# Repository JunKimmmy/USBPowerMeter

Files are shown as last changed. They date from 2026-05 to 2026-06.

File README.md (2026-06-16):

# USB-C Power Meter

<p align="center">
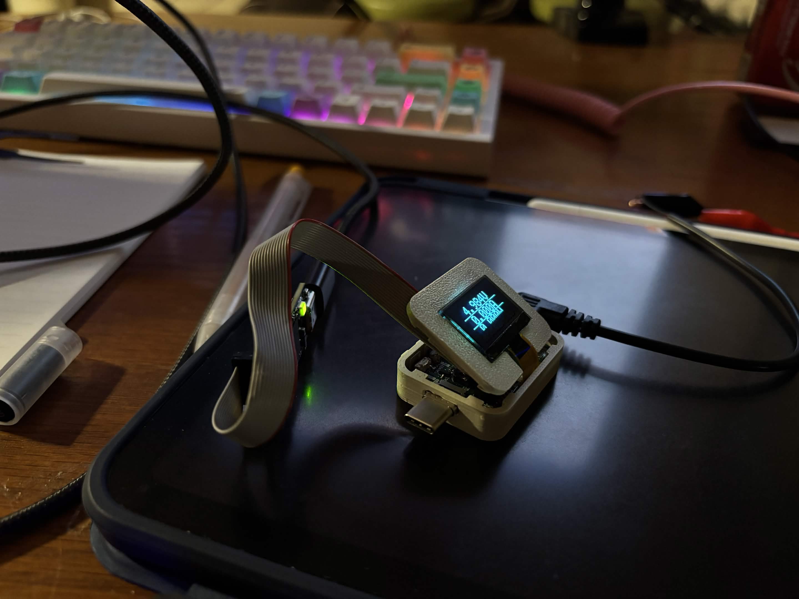
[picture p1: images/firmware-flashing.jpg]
Device running in enclosure
  
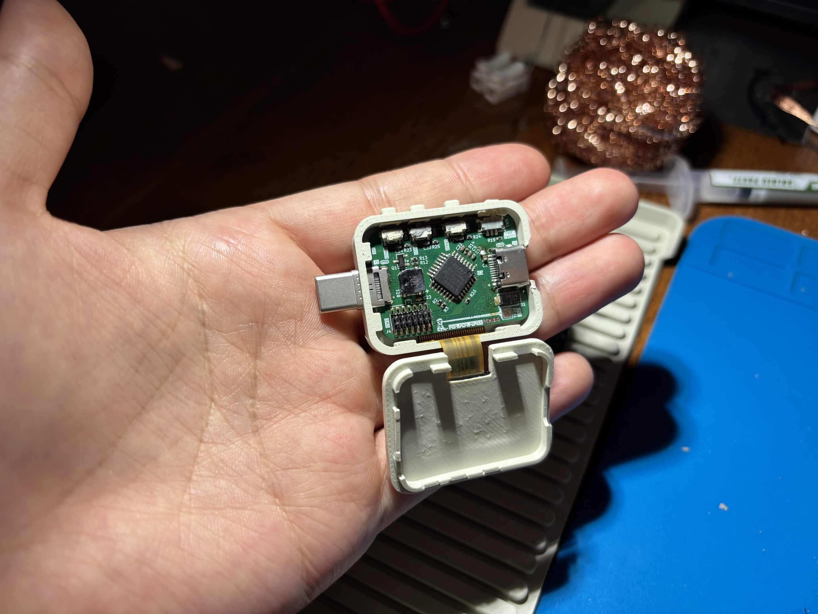
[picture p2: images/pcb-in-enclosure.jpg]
PCB inside open enclosure
  
</p>
<p align="center">
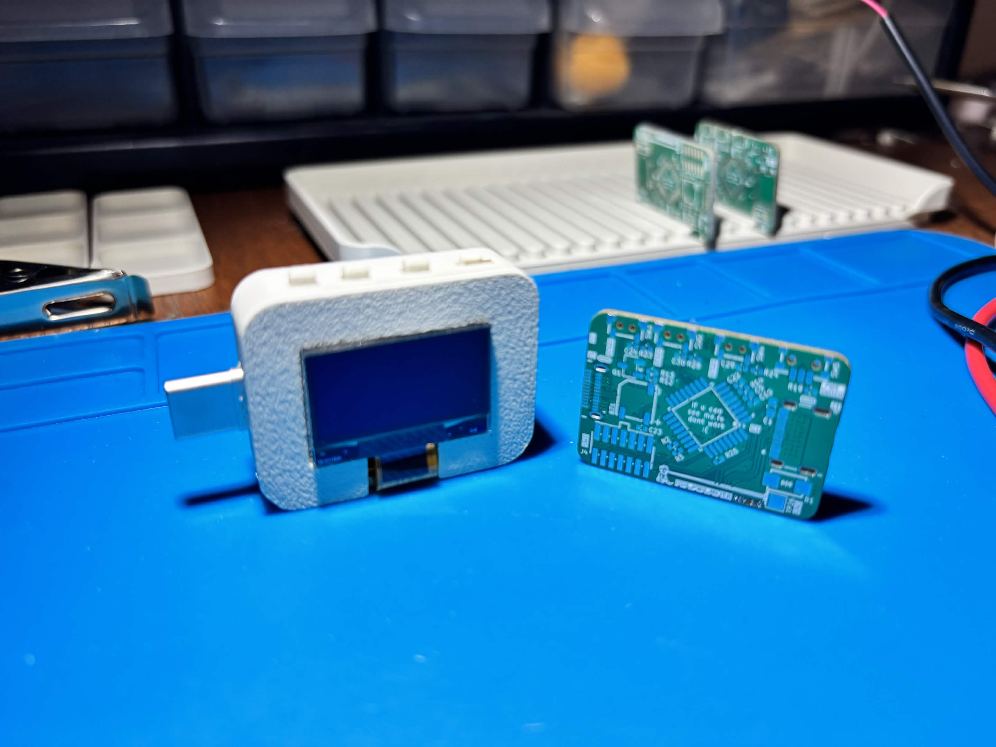
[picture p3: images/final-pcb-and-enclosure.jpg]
Finished enclosure and bare PCB
  
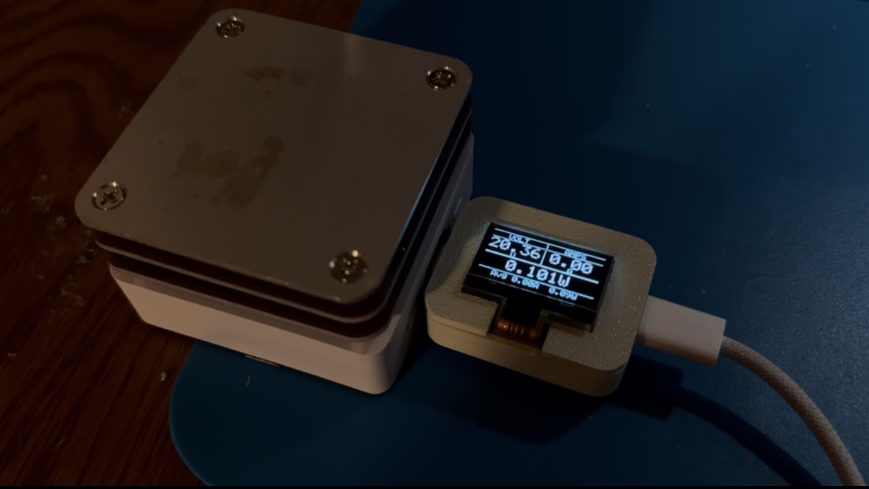
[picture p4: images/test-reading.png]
Device reading power from mini hotplate
  
</p>

A compact USB-C passthrough power meter that displays real-time voltage, current, and power on an integrated 128×64 OLED screen. It sits inline between a USB-C charger and a device — all USB signals pass through transparently while the onboard MCU samples the INA238 power monitor and drives the display.

---

## Features

- **Real-time readout** — voltage, current, and power updated continuously
- **Rolling graphs** — 128-sample circular-buffer plots for current and power with live, average, and peak annotations
- **Running averages** — displayed in the footer of the main meter screen
- **Boot animation** and **dancing-banana easter egg**
- **Buzzer** with user-configurable tones and mute toggle
- **Power switch** and **navigation buttons** for menu control
- Full USB-C signal passthrough (VBUS + data lines)

---

## Specifications

| Parameter | Value |
|---|---|
| Input voltage range | 0.3 V – 48 V |
| Max continuous current | 5 A |
| ADC resolution | 16-bit (INA238) |
| Display | 128×64 OLED (SSD1315), I²C |
| MCU | STM32G030K6T6 (LQFP-32) |
| MCU/peripheral supply | 3.3 V buck from VBUS |
| OLED supply | 3.8 V boost |
| Passthrough | USB-C male + USB-C female |

---

## PCB

<p align="center">
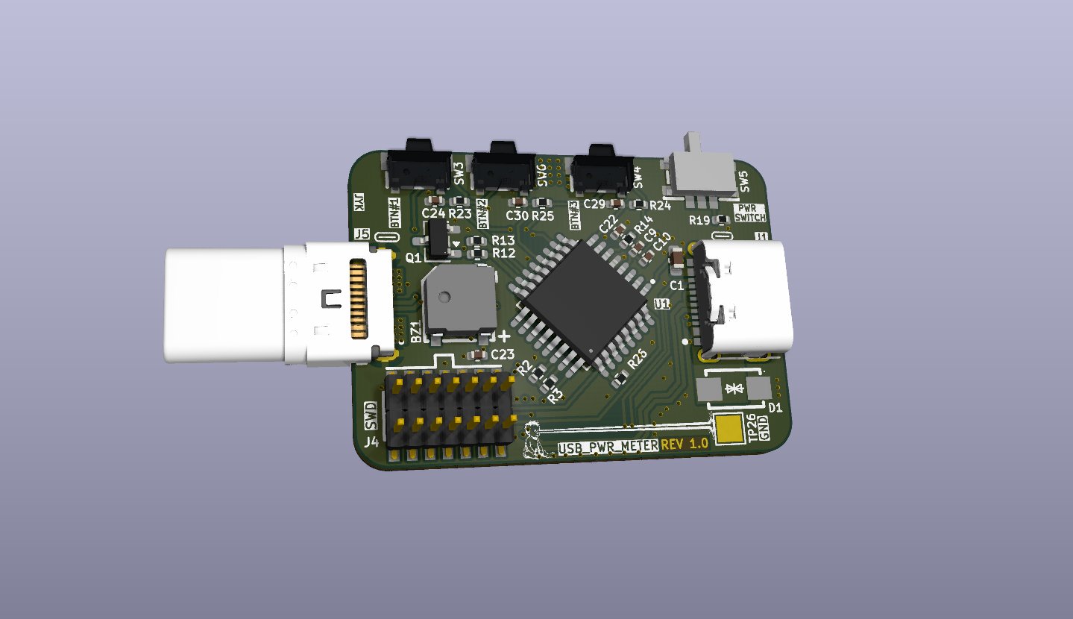
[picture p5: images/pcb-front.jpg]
PCB front — component side
  
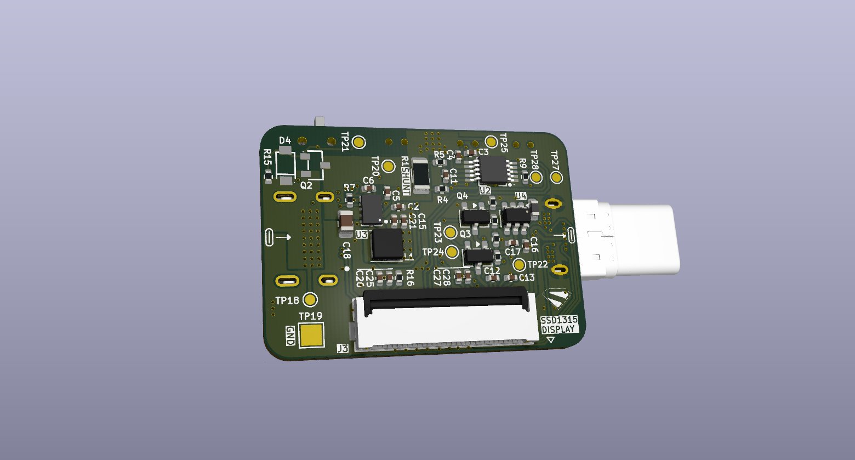
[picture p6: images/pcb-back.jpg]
PCB back — power supply side
  
</p>

Designed in **KiCad 10**. All custom symbols and footprints are in `libs/`.

### Key ICs

| IC | Function |
|----|---|
| INA238 | 16-bit high-precision power/current/voltage monitor (shunt + bus voltage) |
| STM32G030K6T6 | Measurement processing, graph engine, display control |
| SSD1315 | 128×64 OLED controller (I²C) |
| LMR36006 | VBUS-to-3.3 V synchronous buck regulator |
| DGS0010A | 3.8 V boost supply for OLED |

---

## Enclosure

<p align="center">
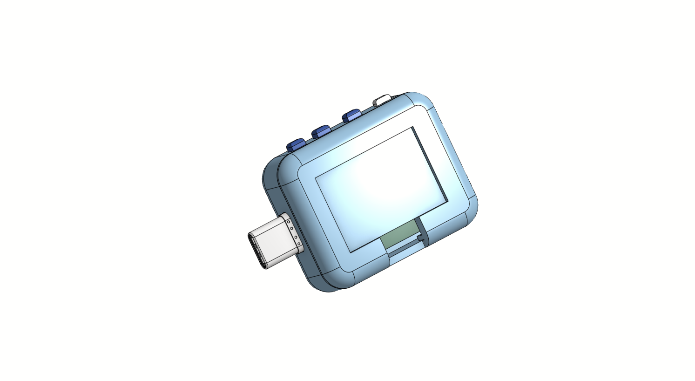
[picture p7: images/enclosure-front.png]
Enclosure front
  
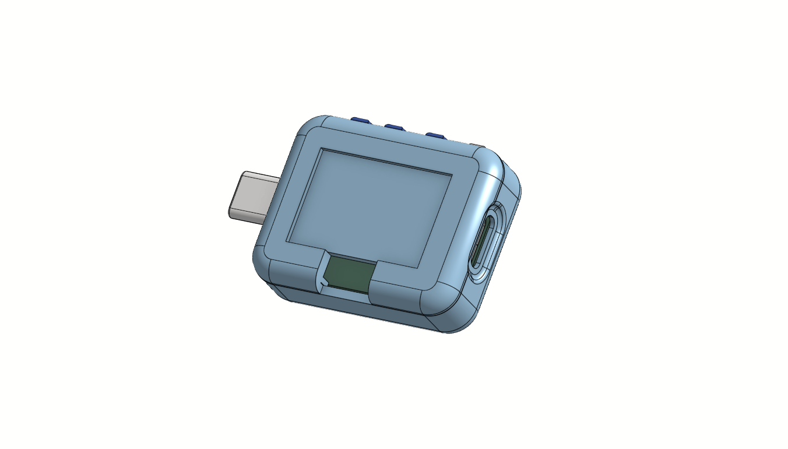
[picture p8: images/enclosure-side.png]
Enclosure side
  
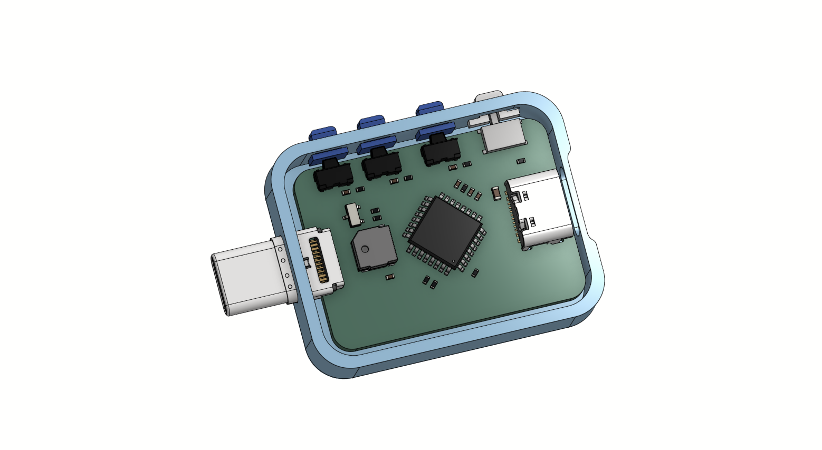
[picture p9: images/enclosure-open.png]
Enclosure open showing PCB
  
</p>
<p align="center">
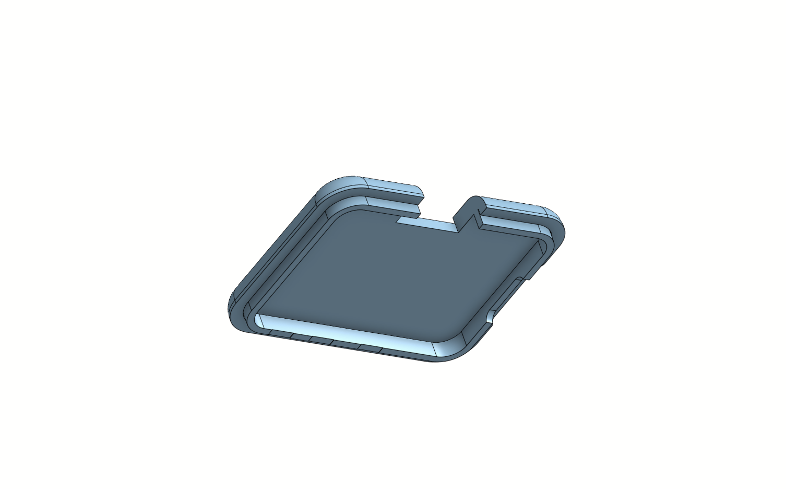
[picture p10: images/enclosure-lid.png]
Enclosure lid
  
</p>

3D-printable enclosure designed in OnShape:
[View in OnShape](https://cad.onshape.com/documents/12768789c7e8d715e02a9c44/w/91224a42db391f032592c489/e/40e560f0614cc0d05faddfcd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)

---

## Build Process

All components were **hand-soldered**. Firmware was flashed over SWD using an **ST-Link V3 Mini**.

<p align="center">
  PCB sitting in open 3D-printed enclosure
  ST-Link V3 Mini connected via SWD ribbon for flashing
</p>

### Videos

| Video | Description |
|---|---|
| [PCB Assembly](videos/pcb-assembly.mp4) | Hand-soldering all components onto the board |
| [Display Testing](videos/display-testing.mp4) | OLED display bring-up and meter UI |
| [Buzzer Testing](videos/buzzer-testing.mp4) | Buzzer tone testing |

---

## Testing

The meter was tested by powering a **mini hotplate** (~20 V supply). The power graph clearly shows the hotplate's heating element ramping up linearly from 0 W as it heats, plateauing around **42 W** once it reaches temperature, then dropping sharply when switched off.

<p align="center">
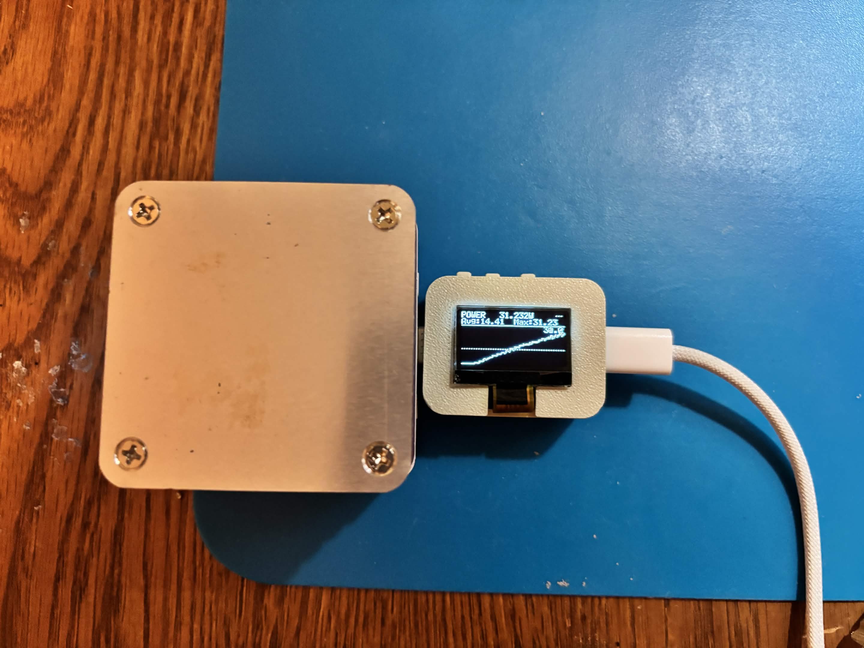
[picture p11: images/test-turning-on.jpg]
Power graph rising as hotplate heats up
  
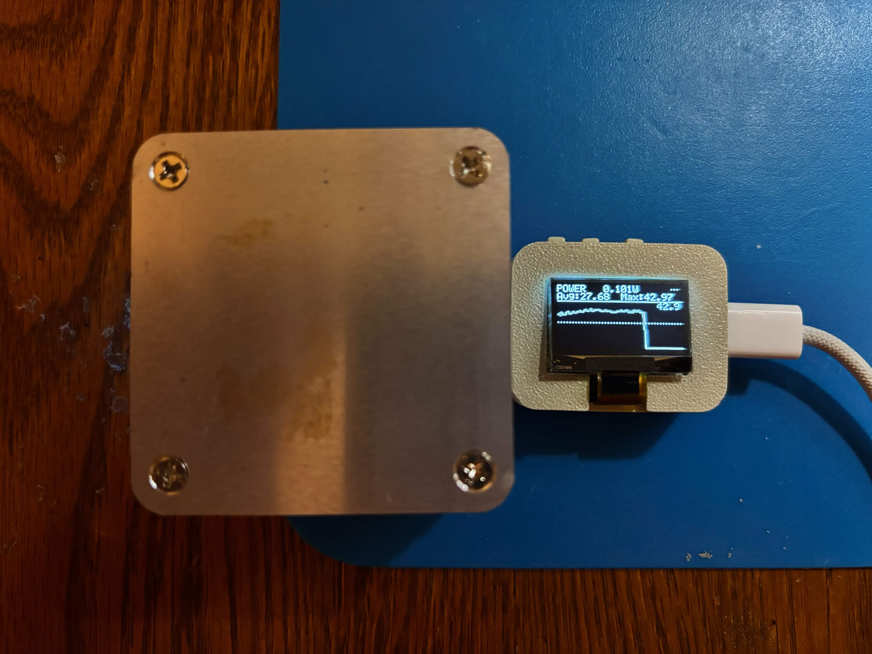
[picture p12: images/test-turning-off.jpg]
Power graph plateauing at ~42 W then dropping when hotplate is switched off
  
</p>
<p align="center">
  Close-up of meter display during hotplate test
</p>

---

## Firmware

Written in C using STM32CubeIDE with the STM32 HAL. Targets the STM32G030K6T6.

### Display Modes

| Mode | Description |
|---|---|
| **Main Meter** | Two-column header (VOLT / AMPS), large 2× readout, full-width power row, footer with running averages |
| **Current Graph** | 128-sample rolling plot of current (mA), dashed line = running average, header shows live + avg + peak |
| **Power Graph** | Same layout as current graph but for power (mW) |

Navigate between modes with the onboard buttons.

### Source Modules

| File | Purpose |
|---|---|
| `main.c` | HAL init, main loop, buzzer tone engine |
| `meter.c` | Display screens, graph circular buffer, button debounce |
| `oled.c` | SSD1315 OLED driver (I²C, page-mode framebuffer) |
| `ina238.c` | INA238 driver — shunt/bus voltage, current, power registers |
| `boot.c` | Animated boot screen |
| `banana.c / banana_frames.c` | Dancing-banana easter egg animation |
| `generate_frames.py` | Converts 249×246 GIF PROGMEM bitmaps to SSD1315 page-format C arrays |

### Building & Flashing

1. Open `Firmware/ST/` in **STM32CubeIDE**
2. Build (Ctrl+B) — targets STM32G030K6T6, `STM32G030K6TX_FLASH.ld`
3. Connect **ST-Link V3 Mini** to the SWD header and flash

---

## Repository Structure

```
USBpowermeter.kicad_pro       KiCad project
USBpowermeter.kicad_sch       Schematic
USBpowermeter.kicad_pcb       PCB layout
libs/
  Library.kicad_sym           Custom schematic symbols
  Library.pretty/             Custom footprints
  3dmodels/                   STEP models for 3D viewer
Firmware/ST/
  Core/Src/                   Application source (C)
  Core/Inc/                   Application headers
  Drivers/                    STM32 HAL + CMSIS
  generate_frames.py          Bitmap conversion tool
images/                       PCB renders, enclosure CAD, real photos
videos/                       Assembly and testing footage
```

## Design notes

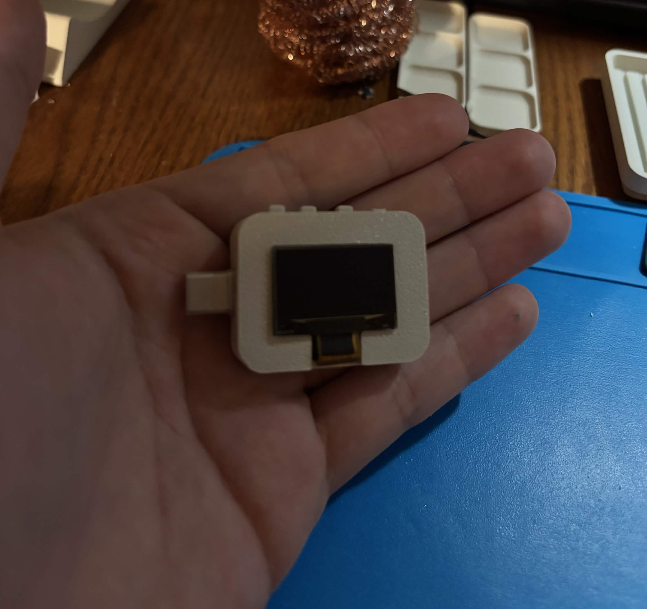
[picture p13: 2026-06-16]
images/final-in-hand.jpg

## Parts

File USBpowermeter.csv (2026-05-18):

Reference | Qty | Value | DNP | Exclude from BOM | Exclude from Board | Footprint | Datasheet | LCSC Part
J1 | 1 | USB4215-03-A |  |  |  | Library_new:CONN_8p94X6p5X3p16_12L_GCC | USB4215-03-A | C37616412
J5 | 1 | USB4155-03-C | DNP |  |  | Library_new:GCT_USB4155-03-C_REVA |  | ORDER ON DIGIKEY
SW3,SW4,SW6 | 3 | TS24CA |  |  |  | Library:SW-SMD_2P-TS24CA |  | C393942
TP19 | 1 | TP5 |  |  |  | TestPoint:TestPoint_Pad_D1.0mm
TP17 | 1 | TP4 |  |  |  | TestPoint:TestPoint_Pad_D1.0mm
U7 | 1 | TLV61046ADBVR |  |  |  | Library:SOT-23-6_L2.9-W1.6-P0.95-LS2.8-BL |  | C464815
U1 | 1 | STM32G030K6T6TR |  |  |  | LIBRARY:LQFP-32_L7.0-W7.0-P0.80-LS9.0-BL |  | C724043
D1 | 1 | SMAJ58CA_C2943847 |  |  |  | Library:SMA_L4.2-W2.6-LS5.0-BI |  | C148235
BZ1 | 1 | MLT-5020 |  |  |  | C94598:BUZ-SMD_L5.0-W5.5-P4.60 |  | C94598
SW5 | 1 | MINI MSK12CO2 |  |  |  | Library:SW-SMD_MSK12CO2 |  | C2681570
U3 | 1 | LMR36006FSC3RNXRQ1 |  |  |  | Library:VQFN-12_L3.0-W2.0-P0.65-BL_TI_RNX |  | C1850337
U2 | 1 | INA238AIDGSR |  |  |  | Library:VSSOP-10_L3.0-W3.0-P0.50-LS4.9-BL |  | C2868250
J4 | 1 | HX PZ1.27-2X7P TP |  |  |  | Library:HDR-SMD_14P-P1.27_HX-PZ1.27-2X7P-TP |  | C41376039
J3 | 1 | FPC-05FB-30PH20 |  |  |  | Library:FPC-SMD_30P-P0.50_FPC-05FB-30PH20 |  | C2856833
Q3 | 1 | FDN338P_C347511 |  |  |  | Library:SOT-23-3_L2.9-W1.3-P1.90-LS2.4-BR |  | C24855
Q4 | 1 | FDN335N |  |  |  | Library:SOT-23-3_L2.9-W1.3-P1.90-LS2.4-BR |  | C241804
D4 | 1 | BZT52C12 |  |  |  | Library:SOD-123_L2.7-W1.6-LS3.7-RD |  | C19077410
Q2 | 1 | BRCS5P06MA |  |  |  | Library:SOT-23-3_L2.9-W1.3-P1.90-LS2.4-BR |  | C914070
Q1 | 1 | 2N7002K_C414015 |  |  |  | Library:SOT-23-3_L2.9-W1.3-P1.90-LS2.4-BR |  | C8545
R16 | 1 | 620kΩ |  |  |  | Resistor_SMD:R_0402_1005Metric |  | C2909373
R19 | 1 | 330kΩ |  |  |  | Resistor_SMD:R_0402_1005Metric |  | C2909349
R12 | 1 | 100Ω |  |  |  | Resistor_SMD:R_0402_1005Metric |  | C2906860
R5,R7,R13 | 3 | 100kΩ |  |  |  | Resistor_SMD:R_0402_1005Metric |  | C2906859
R20,R21 | 2 | 47kΩ |  |  |  | Resistor_SMD:R_0402_1005Metric |  | C2906872
R17 | 1 | 38.3kΩ |  |  |  | Resistor_SMD:R_0402_1005Metric |  | C5126223
R9,R14,R18,R23,R24,R25 | 6 | 10kΩ |  |  |  | Resistor_SMD:R_0402_1005Metric |  | C2906861
R1 | 1 | 5mΩ |  |  |  | Resistor_SMD:R_1206_3216Metric |  | C2988648
R2,R3 | 2 | 4.7kΩ |  |  |  | Resistor_SMD:R_0402_1005Metric |  | C105871
R6,R15 | 2 | 1MΩ |  |  |  | Resistor_SMD:R_0402_1005Metric |  | C2909328
L1 | 1 | 22uH |  |  |  | Inductor_SMD:L_APV_ANR3015 |  | C6364792
L2 | 1 | 10uH |  |  | Excluded from board | Inductor_SMD:L_0603_1608Metric |  | C713281
C15,C21 | 2 | 10uF |  |  |  | Capacitor_SMD:C_0402_1005Metric |  | C15525
C20,C25 | 2 | 4.7uF |  |  |  | Capacitor_SMD:C_0402_1005Metric |  | C318563
C26 | 1 | 2.2uF |  |  |  | Capacitor_SMD:C_0402_1005Metric |  | C12530
C2,C4,C6,C10,C12,C13,C19,C27,C28 | 9 | 1uF |  |  |  | Capacitor_SMD:C_0402_1005Metric |  | C42371686
C1,C3,C5,C9,C22,C23 | 6 | 100nF |  |  |  | Capacitor_SMD:C_0402_1005Metric |  | C343042
C24,C29,C30 | 3 | 10nF |  |  |  | Capacitor_SMD:C_0402_1005Metric |  | C22400107

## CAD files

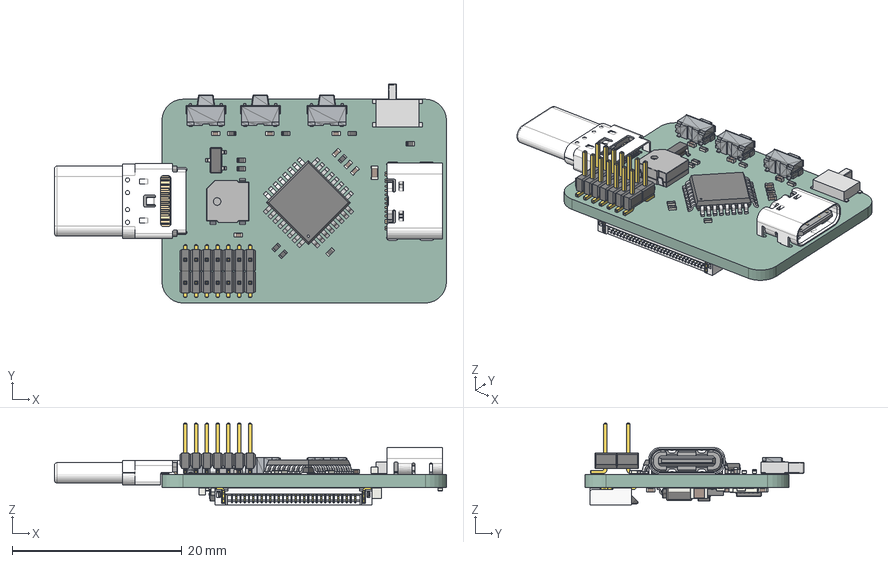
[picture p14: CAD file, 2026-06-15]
.step
46.1 x 25.8 x 9.65 mm
Scale (Solid) x 3
R_0402_1005Metric x 20
C_0402_1005Metric x 23
SOT-23-3 x 3
CUI_DEVICES_CMT-0502-75-SMT-TR
C_0603_1608Metric
ÊäÈë1 x 7
ÇÐ³ý-ÀÉì2
HSG_ASM_1
L_0603_1608Metric
L_APV_ANR3015
SOT-23-6
R_1206_3216Metric
C_0805_2012Metric
LMR36015FSC3RNXTQ1
BODY-SO
LEAD-SO x 10
PIN1-ID
USBpowermeter_PCB

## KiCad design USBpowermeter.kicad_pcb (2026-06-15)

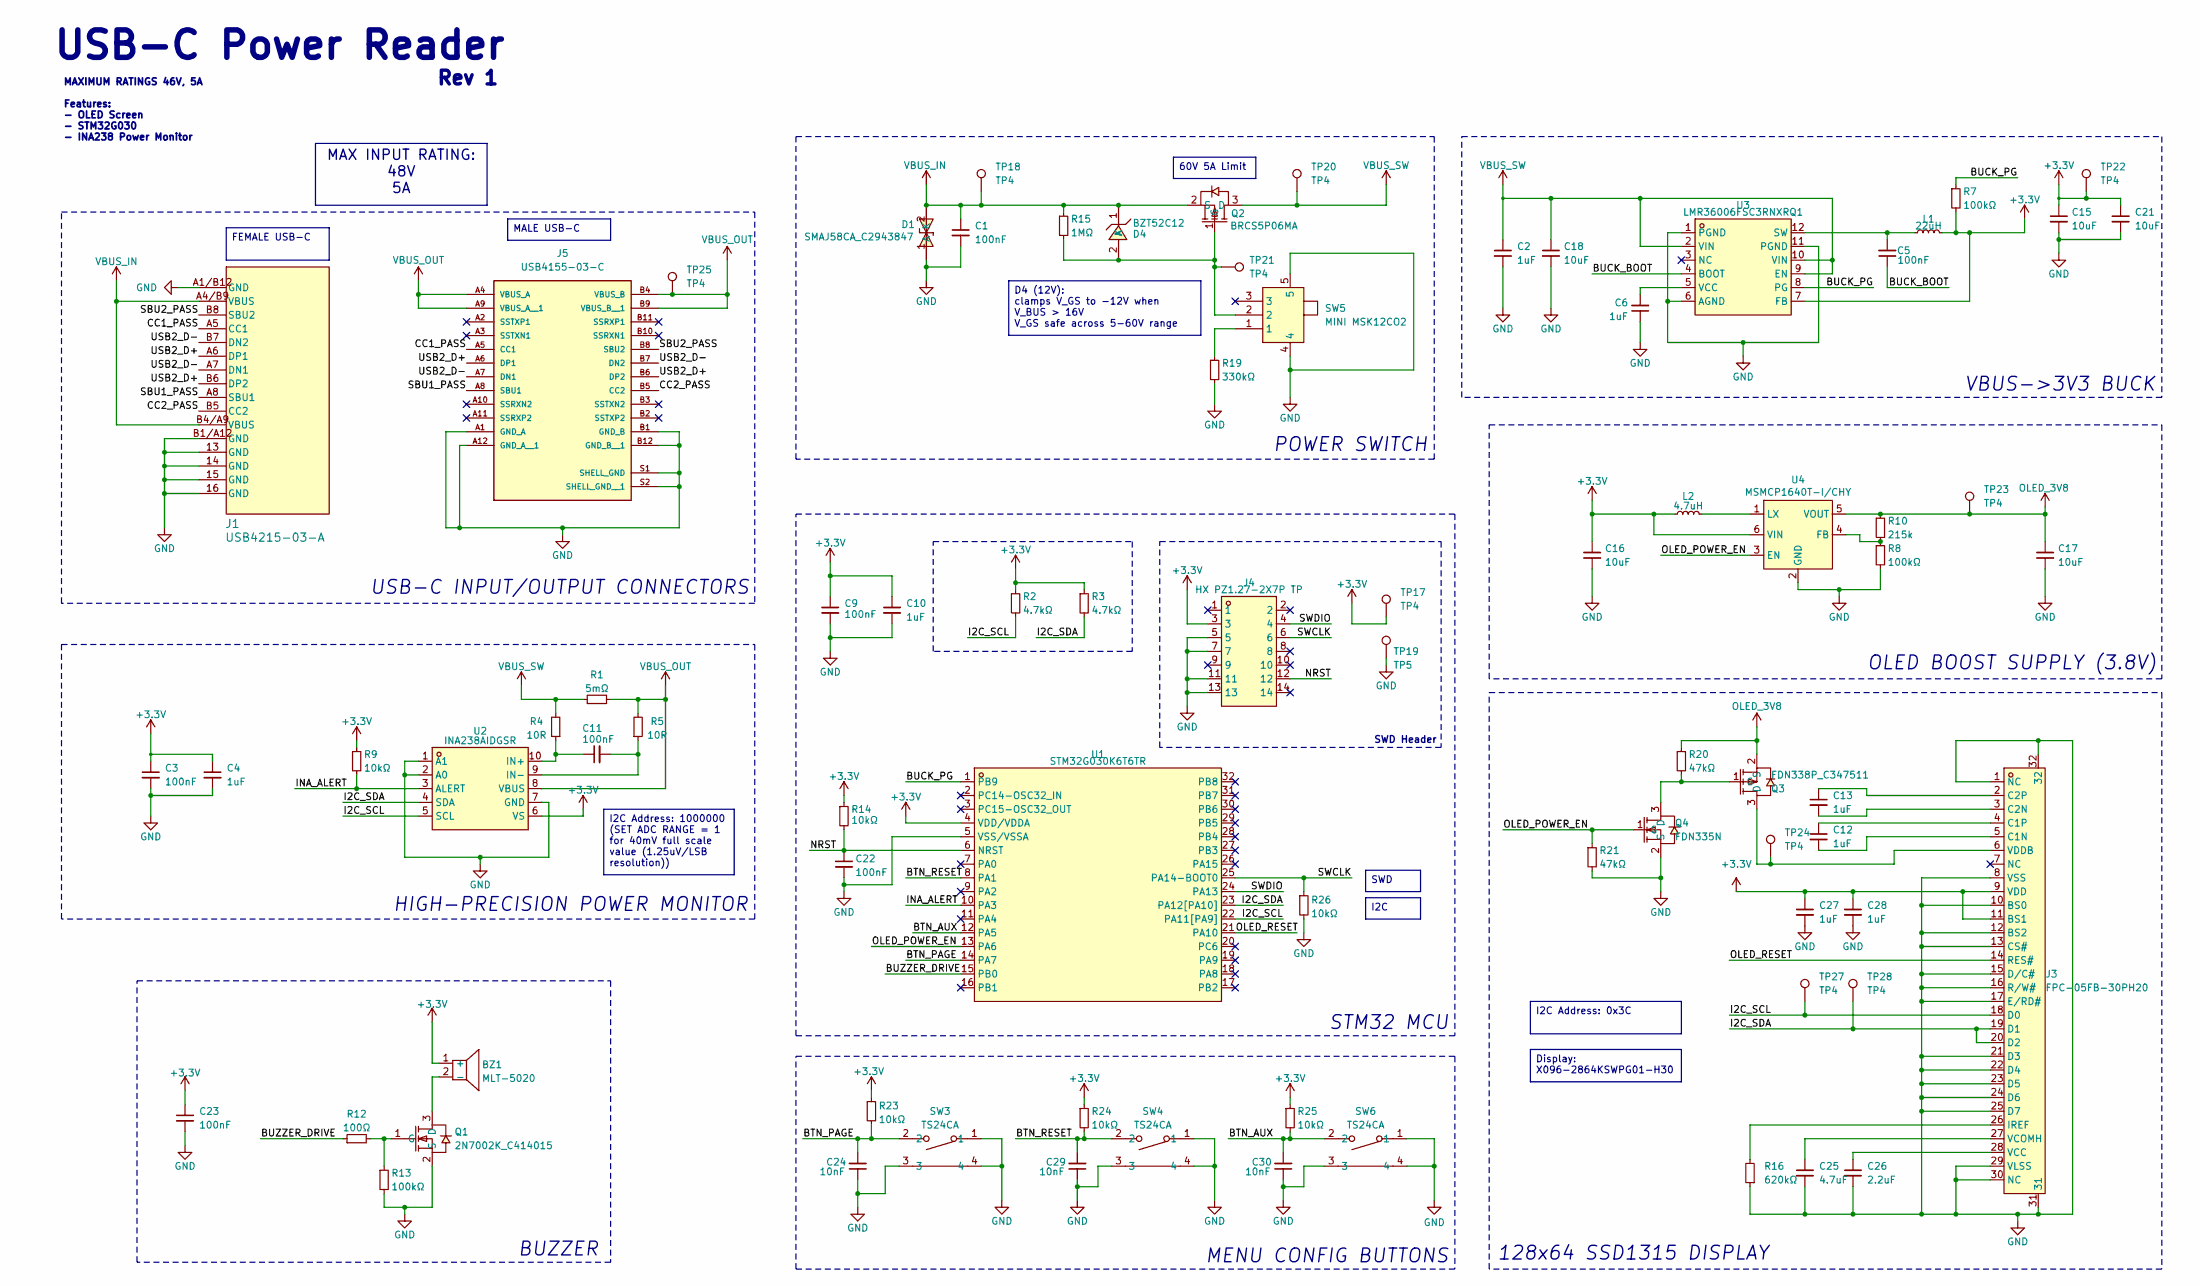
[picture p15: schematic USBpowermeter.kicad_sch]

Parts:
BZ1: MLT-5020; BUZ-SMD_L5.0-W5.5-P4.60; LCSC Part C94598
C1: 100nF; C_0603_1608Metric; LCSC Part C77058
C2, C4, C6, C10, C12, C13, C27, C28: 1uF; C_0402_1005Metric; LCSC Part C42371686
C3, C5, C9, C11, C22, C23: 100nF; C_0402_1005Metric; LCSC Part C343042
C15, C16, C17, C21: 10uF; C_0402_1005Metric; LCSC Part C15525
C18: 10uF; C_0805_2012Metric; LCSC Part C22367830
C24, C29, C30: 10nF; C_0402_1005Metric; LCSC Part C22400107
C25: 4.7uF; C_0402_1005Metric; LCSC Part C318563
C26: 2.2uF; C_0402_1005Metric; LCSC Part C12530
D1: SMAJ58CA_C2943847; SMA_L4.2-W2.6-LS5.0-BI; LCSC Part C148235
D4: BZT52C12; SOD-123_L2.7-W1.6-LS3.7-RD; LCSC Part C19077410
J1: USB4215-03-A; CONN_8p94X6p5X3p16_12L_GCC; LCSC Part C37616412
J3: FPC-05FB-30PH20; FPC-SMD_30P-P0.50_FPC-05FB-30PH20; LCSC Part C2856833
J4: HX PZ1.27-2X7P TP; HDR-SMD_14P-P1.27_HX-PZ1.27-2X7P-TP; LCSC Part C41376039
J5: USB4155-03-C; GCT_USB4155-03-C_REVA; PARTREV A; LCSC Part ORDER ON DIGIKEY
L1: 22uH; L_APV_ANR3015; LCSC Part C6364792
L2: 4.7uH; L_0603_1608Metric; LCSC Part C295681
Q1: 2N7002K_C414015; SOT-23-3; LCSC Part C8545
Q2: BRCS5P06MA; SOT-23-3_L2.9-W1.3-P1.90-LS2.4-BR; LCSC Part C914070
Q3: FDN338P_C347511; SOT-23-3; LCSC Part C24855
Q4: FDN335N; SOT-23-3; LCSC Part C241804
R1: 5mΩ; R_1206_3216Metric; LCSC Part C2988648
R2, R3: 4.7kΩ; R_0402_1005Metric; LCSC Part C105871
R4, R5: 10R; R_0402_1005Metric; LCSC Part C2906862
R7, R8, R13: 100kΩ; R_0402_1005Metric; LCSC Part C2906859
R9, R14, R23, R24, R25, R26: 10kΩ; R_0402_1005Metric; LCSC Part C2906861
R10: 215k; R_0402_1005Metric; LCSC Part C3013158
R12: 100Ω; R_0402_1005Metric; LCSC Part C2906860
R15: 1MΩ; R_0402_1005Metric; LCSC Part C2909328
R16: 620kΩ; R_0402_1005Metric; LCSC Part C2909373
R19: 330kΩ; R_0402_1005Metric; LCSC Part C2909349
R20, R21: 47kΩ; R_0402_1005Metric; LCSC Part C2906872
SW3, SW4, SW6: TS24CA; SW-SMD_2P-TS24CA; LCSC Part C393942
SW5: MINI MSK12CO2; SW-SMD_MSK12CO2; LCSC Part C2681570
TP17, TP18, TP20, TP21, TP22, TP23, TP24, TP25, TP27, TP28: TP4; TestPoint_Pad_D1.0mm
TP19: TP5; TestPoint_Pad_D1.0mm
U1: STM32G030K6T6TR; LQFP-32_L7.0-W7.0-P0.80-LS9.0-BL; LCSC Part C724043
U2: INA238AIDGSR; VSSOP-10_L3.0-W3.0-P0.50-LS4.9-BL; LCSC Part C2868250
U3: LMR36006FSC3RNXRQ1; VQFN-12_L3.0-W2.0-P0.65-BL_TI_RNX; LCSC Part C1850337
U4: MSMCP1640T-I/CHY; SOT-23-6; LCSC Part C49208392

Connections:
+3.3V: BZ1.1 (+), C3.1, C4.1, C9.1, C10.1, C15.1, C16.1, C21.1, C23.1, C27.1, C28.1, J3.9 (VDD), J3.11 (BS1), J4.3, L1.2, L2.1, R2.1, R3.1, R7.2, R9.1, R14.1, R23.1, R24.1, R25.1, TP17.1, TP22.1 (1_1), U1.4 (VDD/VDDA), U2.6 (VS), U3.7 (FB), U4.6 (VIN)
/BTN_AUX: C30.2, R25.2, SW6.2, U1.12 (PA5)
/BTN_PAGE: C24.2, R23.2, SW3.2, U1.14 (PA7)
/BTN_RESET: C29.2, R24.2, SW4.2, U1.8 (PA1)
/BUCK_BOOT: C5.1, U3.4 (BOOT)
/BUCK_PG: R7.1, U1.1 (PB9), U3.8 (PG)
/BUZZER_DRIVE: R12.1, U1.15 (PB0)
/CC1_PASS: J1.A5 (CC1), J5.A5 (CC1)
/CC2_PASS: J1.B5 (CC2), J5.B5 (CC2)
/I2C_SCL: J3.18 (D0), R2.2, TP27.1 (1_1), U1.22 (PA11[PA9]), U2.5 (SCL)
/I2C_SDA: J3.19 (D1), J3.20 (D2), R3.2, TP28.1 (1_1), U1.23 (PA12[PA10]), U2.4 (SDA)
/INA_ALERT: R9.2, U1.10 (PA3), U2.3 (ALERT)
/NRST: C22.1, J4.12, R14.2, U1.6 (NRST)
/OLED_POWER_EN: Q4.1 (G), R21.1, U1.13 (PA6), U4.3 (EN)
/OLED_RESET: J3.14 (RES#), U1.21 (PA10)
/SBU1_PASS: J1.A8 (SBU1), J5.A8 (SBU1)
/SBU2_PASS: J1.B8 (SBU2), J5.B8 (SBU2)
/SWCLK: J4.6, R26.1, U1.25 (PA14-BOOT0)
/SWDIO: J4.4, U1.24 (PA13)
/USB2_D+: J1.A6 (DP1), J1.B6 (DP2), J5.A6 (DP1), J5.B6 (DP2)
/USB2_D-: J1.A7 (DN1), J1.B7 (DN2), J5.A7 (DN1), J5.B7 (DN2)
GND: C1.2, C2.2, C3.2, C4.2, C6.1, C9.2, C10.2, C15.2, C16.2, C17.2, C18.2, C21.2, C22.2, C23.2, C24.1, C25.2, C26.2, C27.2, C28.2, C29.1, C30.1, D1.1 (K), J1.13 (GND), J1.14 (GND), J1.15 (GND), J1.16 (GND), J1.A1/B12 (GND), J1.B1/A12 (GND), J3.1 (NC), J3.8 (VSS), J3.10 (BS0), J3.12 (BS2), J3.13 (CS#), J3.15 (D/C#), J3.16 (R/W#), J3.17 (E/RD#), J3.21 (D3), J3.22 (D4), J3.23 (D5), J3.24 (D6), J3.25 (D7), J3.29 (VLSS), J3.30 (NC), J3.31, J3.32, J4.5, J4.7, J4.11, J4.13, J5.A1 (GND_A), J5.A12 (GND_A__1), J5.B1 (GND_B), J5.B12 (GND_B__1), J5.S1 (SHELL_GND), J5.S2 (SHELL_GND__1), Q1.2 (S), Q4.2 (S), R8.2, R13.2, R16.1, R19.2, R21.2, R26.2, SW3.1, SW3.3, SW3.4, SW4.1, SW4.3, SW4.4, SW5.4, SW5.5, SW6.1, SW6.3, SW6.4, TP19.1 (1_1), U1.5 (VSS/VSSA), U2.1 (A1), U2.2 (A0), U2.7 (GND), U3.1 (PGND), U3.6 (AGND), U3.11 (PGND), U4.2 (GND); also elsewhere on the board
unnamed: BZ1.2 (-), Q1.3 (D)
unnamed: D4.2 (A), Q2.1 (G), R15.2, SW5.2, TP21.1 (1_1)
unnamed: C12.2, J3.5 (C1N)
unnamed: C12.1, J3.4 (C1P)
unnamed: C13.2, J3.3 (C2N)
unnamed: C13.1, J3.2 (C2P)
unnamed: J3.26 (IREF), R16.2
unnamed: C26.1, J3.28 (VCC)
unnamed: C25.1, J3.27 (VCOMH)
unnamed: J3.6 (VDDB), Q3.3 (D), TP24.1 (1_1)
unnamed: Q1.1 (G), R12.2, R13.1
unnamed: Q3.1 (G), Q4.3 (D), R20.2
unnamed: R19.1, SW5.1
unnamed: C11.1, R4.1, U2.10 (IN+)
unnamed: C11.2, R5.1, U2.9 (IN-)
unnamed: C5.2, L1.1, U3.12 (SW)
unnamed: C6.2, U3.5 (VCC)
unnamed: R8.1, R10.2, U4.4 (FB)
unnamed: L2.2, U4.1 (LX)
OLED_3V8: C17.1, Q3.2 (S), R10.1, R20.1, TP23.1 (1_1), U4.5 (VOUT)
VBUS_IN: C1.1, D1.2 (A), D4.1 (K), J1.A4/B9 (VBUS), J1.B4/A9 (VBUS), Q2.2 (S), R15.1, TP18.1 (1_1)
VBUS_OUT: J5.A4 (VBUS_A), J5.A9 (VBUS_A__1), J5.B4 (VBUS_B), J5.B9 (VBUS_B__1), R1.2, R5.2, TP25.1 (1_1), U2.8 (VBUS)
VBUS_SW: C2.1, C18.1, Q2.3 (D), R1.1, R4.2, TP20.1 (1_1), U3.2 (VIN), U3.9 (EN), U3.10 (VIN)

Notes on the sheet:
BUZZER
USB-C INPUT/OUTPUT CONNECTORS
STM32 MCU
POWER SWITCH
HIGH-PRECISION POWER MONITOR
SWD Header
OLED BOOST SUPPLY (3.8V)
VBUS->3V3 BUCK
MAXIMUM RATINGS 46V, 5A Features: - OLED Screen - STM32G030 - INA238 Power Monitor
Rev 1
128x64 SSD1315 DISPLAY
MENU CONFIG BUTTONS
USB-C Power Reader
60V 5A Limit
D4 (12V): clamps V_GS to -12V when V_BUS > 16V V_GS safe across 5-60V range
I2C Address: 0x3C
Display: X096-2864KSWPG01-H30
FEMALE USB-C
I2C
SWD
MAX INPUT RATING: 48V 5A
I2C Address: 1000000 (SET ADC RANGE = 1 for 40mV full scale value (1.25uV/LSB resolution))
MALE USB-C

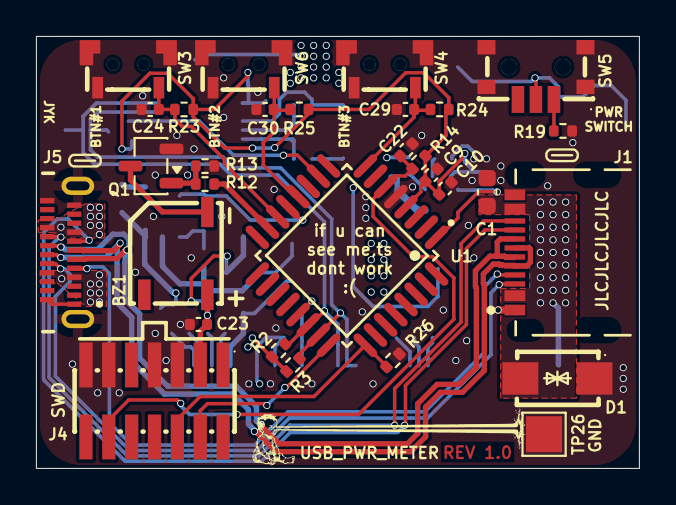
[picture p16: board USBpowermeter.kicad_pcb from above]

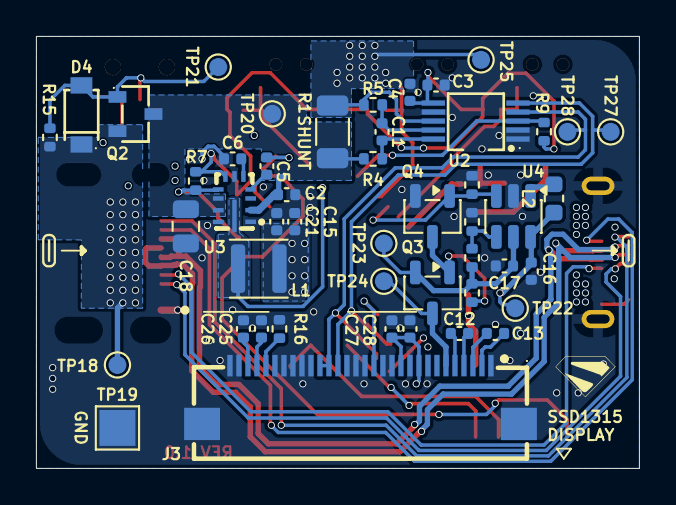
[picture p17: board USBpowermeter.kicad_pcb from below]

Board: 4 copper layers, 33.5 x 24.0 mm, 78 parts (48 on the bottom side), 45 nets.

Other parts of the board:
TP26: TP5; TestPoint_Pad_2.0x2.0mm

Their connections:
GND: TP26.1 (1_1); also elsewhere on the board

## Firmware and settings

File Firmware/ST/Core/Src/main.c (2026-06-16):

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
/* Includes ------------------------------------------------------------------*/
#include "main.h"

/* USER CODE BEGIN Includes */
#include "oled.h"
#include "ina238.h"
#include "banana.h"
#include "boot.h"
#include "meter.h"
#include <stdio.h>
/* USER CODE END Includes */

/* USER CODE BEGIN PD */
#define NOTE_C4   262
#define NOTE_D4   294
#define NOTE_E4   330
#define NOTE_F4   349
#define NOTE_G4   392
#define NOTE_A4   440
#define NOTE_B4   494
#define NOTE_C5   523
#define NOTE_D5   587
#define NOTE_E5   659
#define NOTE_F5   698
#define NOTE_G5   784
#define NOTE_REST 0

#define Q   300
#define H   600
#define DQ  450
#define E8  150
/* USER CODE END PD */

I2C_HandleTypeDef hi2c2;

TIM_HandleTypeDef htim3;

/* USER CODE BEGIN PV */
uint8_t g_muted = 0;
/* USER CODE END PV */

void SystemClock_Config(void);
static void MX_GPIO_Init(void);
static void MX_I2C2_Init(void);
static void MX_TIM3_Init(void);
/* USER CODE BEGIN PFP */
void Buzzer_Tone(uint32_t freq_hz, uint32_t duration_ms);
void Buzzer_Off(void);
void Play_Song1(void);
void Play_Song2(void);
void Play_Song3(void);
void HEV_Boot_Sound(void);
/* USER CODE END PFP */

/**
  * @brief  The application entry point.
  * @retval int
  */
int main(void)
{

  /* MCU Configuration--------------------------------------------------------*/

  /* Reset of all peripherals, Initializes the Flash interface and the Systick. */
  HAL_Init();

  /* Configure the system clock */
  SystemClock_Config();

  /* Initialize all configured peripherals */
  MX_GPIO_Init();
  MX_I2C2_Init();
  MX_TIM3_Init();
  /* USER CODE BEGIN 2 */
  HAL_GPIO_WritePin(OLED_RESET_GPIO_Port, OLED_RESET_Pin, GPIO_PIN_RESET);
  HAL_GPIO_WritePin(OLED_POWER_EN_GPIO_Port, OLED_POWER_EN_Pin, GPIO_PIN_SET);
  HAL_Delay(100);
  HAL_GPIO_WritePin(OLED_RESET_GPIO_Port, OLED_RESET_Pin, GPIO_PIN_SET);
  HAL_Delay(10);
  OLED_Init();
  if (INA238_Init() != HAL_OK)
  {
      OLED_WriteString(3, 0, "INA238 init fail");
      HAL_Delay(2000);
      OLED_Clear();
  }
  HEV_Boot_Sound();
  BOOT_Run();   /* one-shot boot screen with graph animation */
  /* USER CODE END 2 */

  /* Infinite loop */
  /* USER CODE BEGIN 3 */
  METER_Run();   /* handles meter + graph screens + Easter-egg dance; never returns */
  /* USER CODE END 3 */
}

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
/* USER CODE BEGIN 4 */


void Buzzer_Off(void)
{
  HAL_TIM_PWM_Stop(&htim3, TIM_CHANNEL_3);
}

void Buzzer_Tone(uint32_t freq_hz, uint32_t duration_ms)
{
  if (freq_hz == NOTE_REST)
  {
    Buzzer_Off();
    HAL_Delay(duration_ms);
    return;
  }
  uint32_t arr = (1000000UL / freq_hz) - 1;
  __HAL_TIM_SET_AUTORELOAD(&htim3, arr);
  __HAL_TIM_SET_COMPARE(&htim3, TIM_CHANNEL_3, arr / 2);
  HAL_TIM_PWM_Start(&htim3, TIM_CHANNEL_3);
  HAL_Delay(duration_ms - 40);
  Buzzer_Off();
  HAL_Delay(40);
}

void Play_Song1(void)
{
  /* Twinkle Twinkle Little Star — BTN_RESET */
  static const uint32_t melody[][2] = {
    {NOTE_C4, Q}, {NOTE_C4, Q}, {NOTE_G4, Q}, {NOTE_G4, Q},
    {NOTE_A4, Q}, {NOTE_A4, Q}, {NOTE_G4, H},
    {NOTE_F4, Q}, {NOTE_F4, Q}, {NOTE_E4, Q}, {NOTE_E4, Q},
    {NOTE_D4, Q}, {NOTE_D4, Q}, {NOTE_C4, H},
    {NOTE_G4, Q}, {NOTE_G4, Q}, {NOTE_F4, Q}, {NOTE_F4, Q},
    {NOTE_E4, Q}, {NOTE_E4, Q}, {NOTE_D4, H},
    {NOTE_G4, Q}, {NOTE_G4, Q}, {NOTE_F4, Q}, {NOTE_F4, Q},
    {NOTE_E4, Q}, {NOTE_E4, Q}, {NOTE_D4, H},
    {NOTE_C4, Q}, {NOTE_C4, Q}, {NOTE_G4, Q}, {NOTE_G4, Q},
    {NOTE_A4, Q}, {NOTE_A4, Q}, {NOTE_G4, H},
    {NOTE_F4, Q}, {NOTE_F4, Q}, {NOTE_E4, Q}, {NOTE_E4, Q},
    {NOTE_D4, Q}, {NOTE_D4, Q}, {NOTE_C4, H},
  };
  for (uint32_t i = 0; i < sizeof(melody) / sizeof(melody[0]); i++)
    Buzzer_Tone(melody[i][0], melody[i][1]);
}

void Play_Song2(void)
{
  /* Happy Birthday — BTN_AUX */
  static const uint32_t melody[][2] = {
    {NOTE_G4, DQ}, {NOTE_G4, E8}, {NOTE_A4, Q}, {NOTE_G4, Q}, {NOTE_C5, Q}, {NOTE_B4, H}, {NOTE_REST, Q},
    {NOTE_G4, DQ}, {NOTE_G4, E8}, {NOTE_A4, Q}, {NOTE_G4, Q}, {NOTE_D5, Q}, {NOTE_C5, H}, {NOTE_REST, Q},
    {NOTE_G4, DQ}, {NOTE_G4, E8}, {NOTE_G5, Q}, {NOTE_E5, Q}, {NOTE_C5, Q}, {NOTE_B4, Q}, {NOTE_A4, H}, {NOTE_REST, Q},
    {NOTE_F5, DQ}, {NOTE_F5, E8}, {NOTE_E5, Q}, {NOTE_C5, Q}, {NOTE_D5, Q}, {NOTE_C5, H},
  };
  for (uint32_t i = 0; i < sizeof(melody) / sizeof(melody[0]); i++)
    Buzzer_Tone(melody[i][0], melody[i][1]);
}

void Play_Song3(void)
{
  /* Mary Had a Little Lamb — BTN_PAGE */
  static const uint32_t melody[][2] = {
    {NOTE_E4, Q}, {NOTE_D4, Q}, {NOTE_C4, Q}, {NOTE_D4, Q},
    {NOTE_E4, Q}, {NOTE_E4, Q}, {NOTE_E4, H},
    {NOTE_D4, Q}, {NOTE_D4, Q}, {NOTE_D4, H},
    {NOTE_E4, Q}, {NOTE_G4, Q}, {NOTE_G4, H},
    {NOTE_E4, Q}, {NOTE_D4, Q}, {NOTE_C4, Q}, {NOTE_D4, Q},
    {NOTE_E4, Q}, {NOTE_E4, Q}, {NOTE_E4, Q}, {NOTE_E4, Q},
    {NOTE_D4, Q}, {NOTE_D4, Q}, {NOTE_E4, Q}, {NOTE_D4, Q},
    {NOTE_C4, H},
  };
  for (uint32_t i = 0; i < sizeof(melody) / sizeof(melody[0]); i++)
    Buzzer_Tone(melody[i][0], melody[i][1]);
}

void HEV_Boot_Sound(void)
{
  /* Rising exponential sweep — simulates HEV capacitor charge */
  static const uint32_t sweep_f[] = { 120, 160, 210, 270, 340, 420, 510, 610, 720, 840 };
  static const uint16_t sweep_d[] = {  55,  45,  38,  32,  28,  25,  23,  22,  22,  60 };
  for (int i = 0; i < 10; i++)
  {
    uint32_t arr = (1000000UL / sweep_f[i]) - 1;
    __HAL_TIM_SET_AUTORELOAD(&htim3, arr);
    __HAL_TIM_SET_COMPARE(&htim3, TIM_CHANNEL_3, arr / 2);
    HAL_TIM_PWM_Start(&htim3, TIM_CHANNEL_3);
    HAL_Delay(sweep_d[i]);
  }
  HAL_TIM_PWM_Stop(&htim3, TIM_CHANNEL_3);
  HAL_Delay(90);

  /* Three ascending confirmation tones — "HEV suit activated" */
  Buzzer_Tone(784,  90);   /* G5 */
  Buzzer_Tone(988,  90);   /* B5 */
  Buzzer_Tone(1319, 220);  /* E6 */
}
/* USER CODE END 4 */
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


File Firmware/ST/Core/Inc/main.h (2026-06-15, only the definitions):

#define BUCK_PG_Pin GPIO_PIN_9
#define BUCK_PG_GPIO_Port GPIOB
#define BTN_RESET_Pin GPIO_PIN_1
#define BTN_RESET_GPIO_Port GPIOA
#define INA_ALERT_Pin GPIO_PIN_3
#define INA_ALERT_GPIO_Port GPIOA
#define BTN_AUX_Pin GPIO_PIN_5
#define BTN_AUX_GPIO_Port GPIOA
#define OLED_POWER_EN_Pin GPIO_PIN_6
#define OLED_POWER_EN_GPIO_Port GPIOA
#define BTN_PAGE_Pin GPIO_PIN_7
#define BTN_PAGE_GPIO_Port GPIOA
#define OLED_RESET_Pin GPIO_PIN_10
#define OLED_RESET_GPIO_Port GPIOA

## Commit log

2026-05-17 Schematic Updates
    [USBpowermeter.kicad_pcb, USBpowermeter.kicad_sch]
2026-05-17 Schem update
    [STM32.kicad_sch.kicad_sch, USB_C_FEMALE.kicad_sch.kicad_sch, USB_C_MALE.kicad_sch.kicad_sch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]
2026-05-18 schematic changes
    [STM32.kicad_sch.kicad_sch, USB_C_FEMALE.kicad_sch.kicad_sch, USB_C_MALE.kicad_sch.kicad_sch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]
2026-05-23 push layout
    [USBpowermeter.kicad_pcb, USBpowermeter.kicad_sch]
2026-05-23 Fabrication Push
    [USBpowermeter.kicad_pcb]
2026-05-23 Final Fab Commit
    [USBpowermeter.kicad_pcb]
2026-06-16 Clean up repo and expand README
    - Remove build artifacts (Debug/) and Claude settings from tracking
    - Update .gitignore to exclude Debug/, .claude/, and IDE workspace files
    - Rewrite README with full feature list, display modes, firmware module table, enclosure OnShape link, and build instructions
    - Stage latest firmware changes (banana.c, main.c, meter.c)
2026-06-16 Restore original hero photos and add PCB+enclosure as third

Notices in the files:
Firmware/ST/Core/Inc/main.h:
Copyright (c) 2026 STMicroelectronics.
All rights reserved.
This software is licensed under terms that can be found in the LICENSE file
